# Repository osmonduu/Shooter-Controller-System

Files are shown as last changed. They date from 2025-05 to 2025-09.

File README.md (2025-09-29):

# Shooter Controller System - Custom controllers for shooting games
A controller system that consists of a physical nerf gun controller player camera, aiming, and shooting and a DDR style movement pad. Maps to mouse and keyboard inputs; comptabile with many different games.

# Download the game
This system was designed in collaboration with the UB Fall 2024 CSE410 Game Development team who designed and developed *The Last Run: Project Hope*, a third person zombie parkour shooter game.  

You can download and try *The Last Run: Project Hope* for yourself [here](https://drive.google.com/file/d/1WXuhYaOuxI4oGxkZMJiWuxGikniIIrsq/view).

# About
This was a senior capstone project completed in Spring 2025 in collaboration with Herbert Acheampong and Nathan Fox.

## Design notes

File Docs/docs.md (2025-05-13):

# Movement Pad Documentation

## Important Parts
- Force Sensitive Resistors, a form of potentiometer that changes resistance with applied pressure.  Purchased from [ddrpad.com](https://ddrpad.com/collections/fsr-sensors/products/force-sensitive-resistor-fsr-sensor-square-interlink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)
- Arduino Leonardo, as it supports the keyboard library.  
- Ten 430 Ohm resistors.  The value of the resistor is important because the lower the resistance, the lower the voltage received by the Arduino.  
- Roughly 36 feet of wire are used, running underneath the pad
## Input Scanning 
The code scans through all 10 FSRs, and stores the state in an integer intended to be read in binary or hex.   If the analogue input of the FSR is above a specific threshold, defined in [conf.hpp](../include/conf.hpp). The number has a total of 10 bits that can change, the 10th bit corresponding to the FSR connected to A9, and the 1st bit corresponds to A0.  Below is a diagram that shows what FSR corresponds to what panel on the board, where the top of the diagram is front of the movement pad. There is also markings identifying what each cell is below the acrylic panels and on the underside of the pad.  

Additionally, cell has a red wire that corresponds to the Arduino Leonardo's data pin for that cell.  For example, there is a red wire labeled with number on some masking tape that says it is from Cell 8.  Therefore, it must go to A8.  All the white wires go to the positive voltage line.  This can be either the Arduino or a separate battery like the 12 Volt Dewalt battery.

Unfortunately, there are only 6 analogue pins that are labeled on the Arduino Leonardo even through it supports up to 12 analogue inputs.  This is because some of the digital ports double as analogue ports. Specifically, [digital pin 4 is A6, pin 6 is A7, pin 8 is A8, pin 9 is A9, pin 10 is A10 and pin 12 is A11](https://www.arduino.cc/reference/tr/language/functions/analog-io/analogread/).  Only pins 4 to 9 are used<sup>1</sup>.

1: **ADDENDUM:**  Due to the wire breaking inside of Pin 9, Cell 9 has been moved to port 10/A10.  

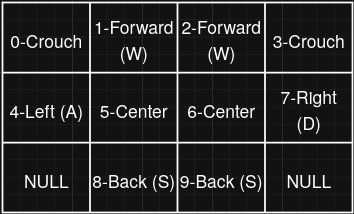
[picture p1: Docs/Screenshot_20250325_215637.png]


## Configuration
Basic configuration can be done in [conf.hpp](../include/conf.hpp).  The threshold value can be configured, and the cells needed to cause a specific action can be changed as well within the define statements.   The code is mostly device agnostic as well.  To define a new device to compile the code to will require updating the [platformio.ini file](../platformio.ini).  This document will not discuss the myriad options provided by Platformio, but you can find that [here.](https://docs.platformio.org/en/latest/)

Additionally, the screwed-in pieces of wood that rest on top of the acrylic panels can be adjusted by screwing in or out the screw.  This can prevent false positives from the wood pushing down the acrylic too tightly.  Changing the threshold can also help.

## Usage

## Common Problems
- Ghost inputs may be caused by the

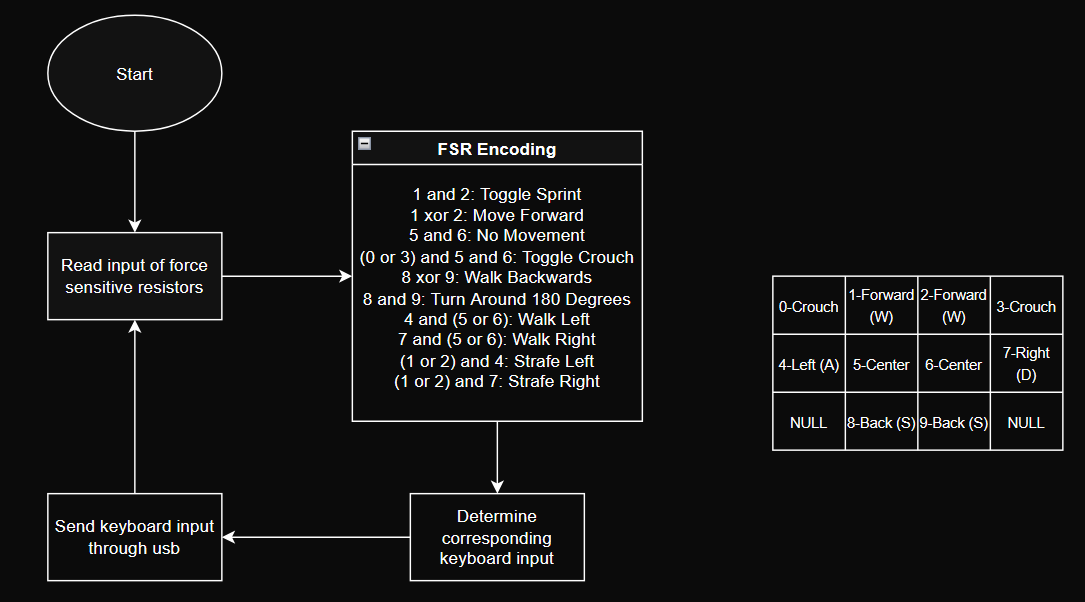
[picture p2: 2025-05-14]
Docs/flowcharts/Flowsheet - Movement Pad.png

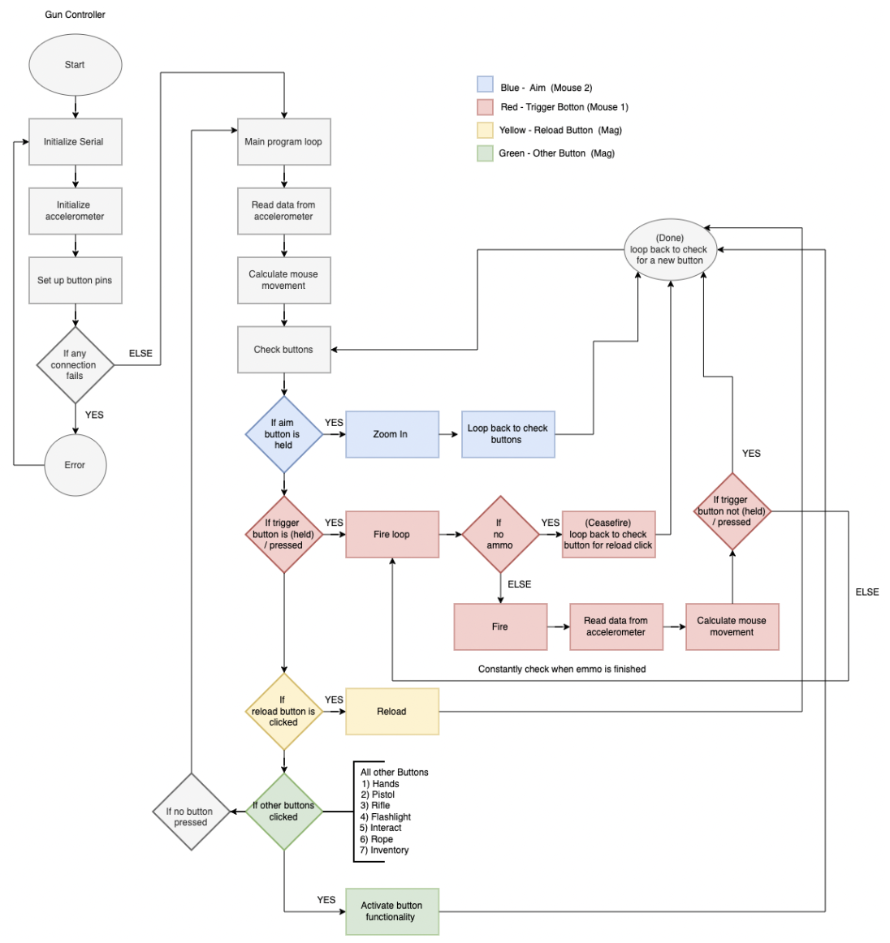
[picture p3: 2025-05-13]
Docs/flowcharts/Flowsheet - Gun Controller.png

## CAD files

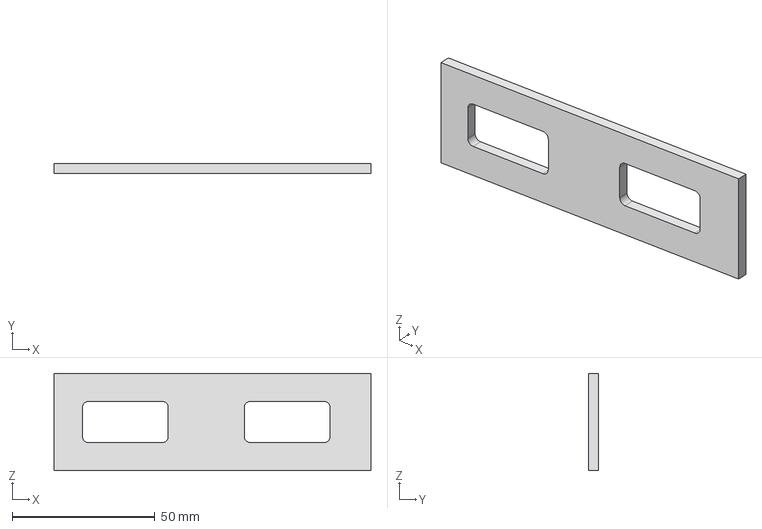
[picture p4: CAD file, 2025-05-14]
3D_Models/arcade_lid_extrusion_3.5.stp
111.0 x 3.50 x 34.0 mm

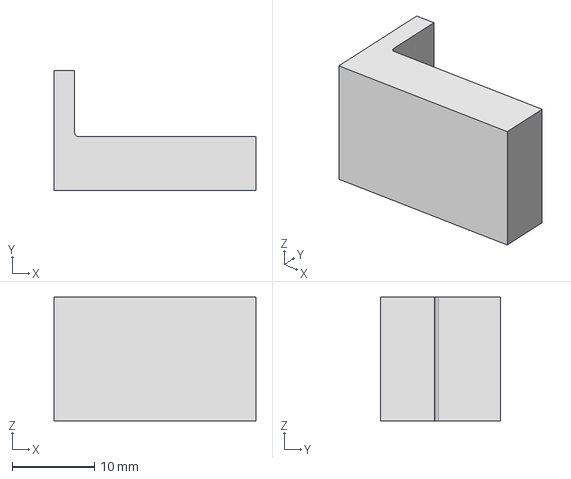
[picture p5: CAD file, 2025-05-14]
3D_Models/small_microswitch_holder.stp
24.5 x 14.5 x 15.0 mm

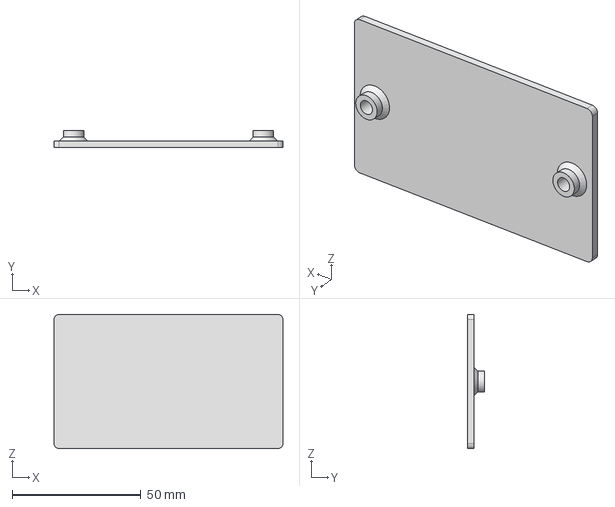
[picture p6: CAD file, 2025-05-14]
3D_Models/medium_backplate.stp
88.9 x 6.50 x 52.1 mm

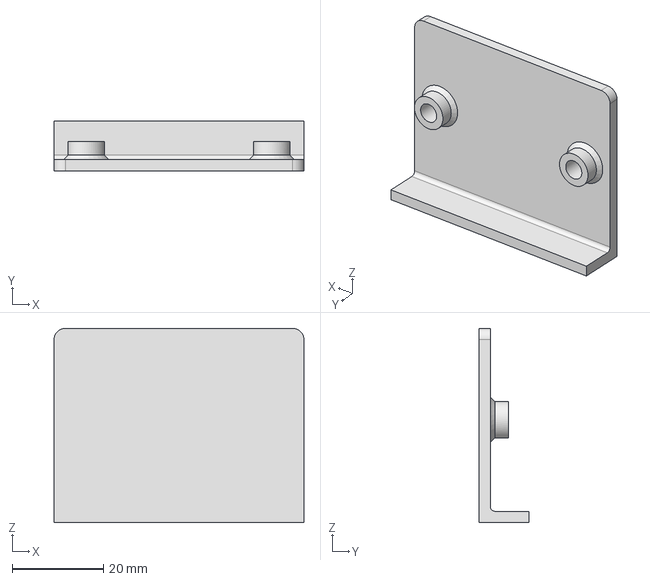
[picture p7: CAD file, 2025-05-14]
3D_Models/small_backplate.stp
54.8 x 11.0 x 42.6 mm

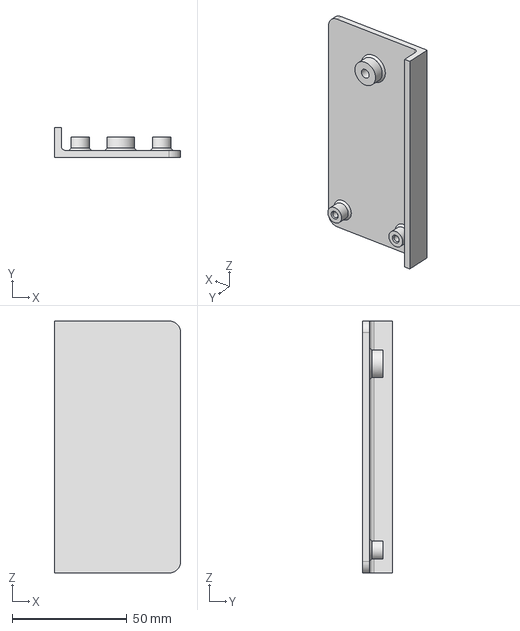
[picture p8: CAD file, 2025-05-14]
3D_Models/long_backplate.stp
55.1 x 13.0 x 110.0 mm

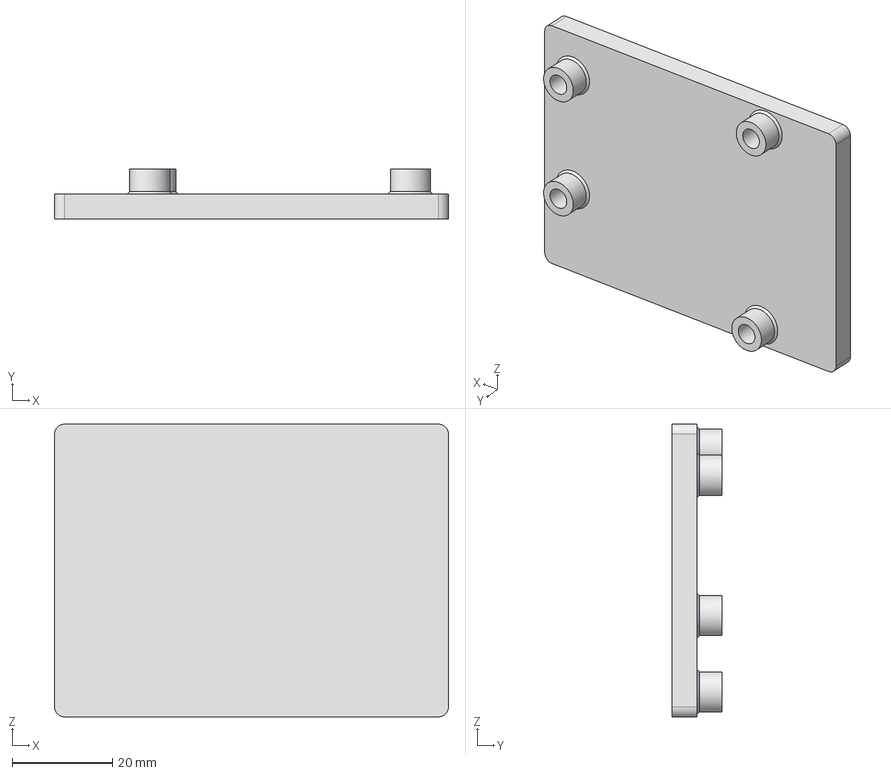
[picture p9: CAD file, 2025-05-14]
3D_Models/leonardo_backplate.stp
78.6 x 10.0 x 58.4 mm

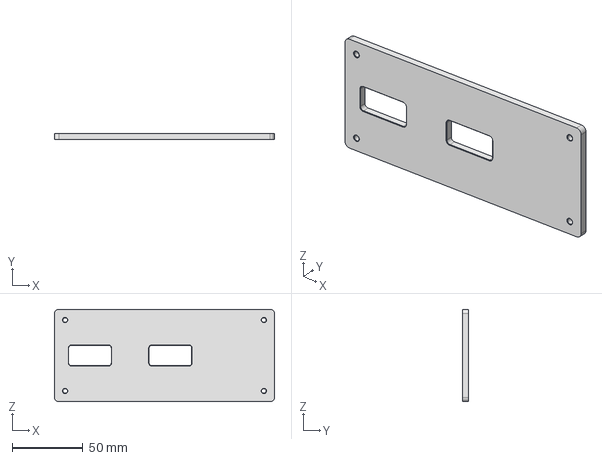
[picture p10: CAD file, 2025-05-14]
3D_Models/arcade_box_lid_iteration3.stp
155.0 x 4.00 x 65.0 mm

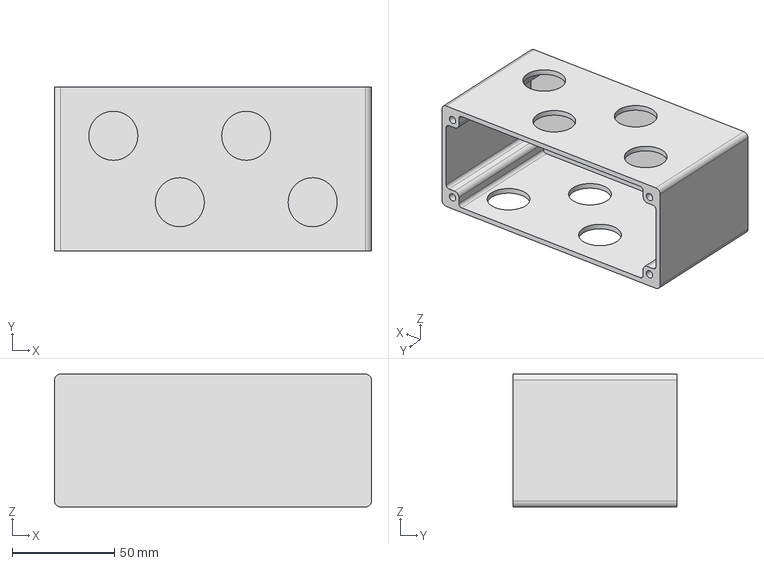
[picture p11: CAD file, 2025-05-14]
3D_Models/arcade_box_iteration3.stp
155.0 x 80.0 x 65.0 mm

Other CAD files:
3D_Models/arcade_box_iteration3.stl
3D_Models/arcade_box_lid_iteration3.stl
3D_Models/arcade_lid_extrusion_3.5.stl
3D_Models/leonardo_backplate.stl
3D_Models/long_backplate.stl
3D_Models/medium_backplate.stl
3D_Models/small_backplate.stl
3D_Models/small_microswitch_holder.stl

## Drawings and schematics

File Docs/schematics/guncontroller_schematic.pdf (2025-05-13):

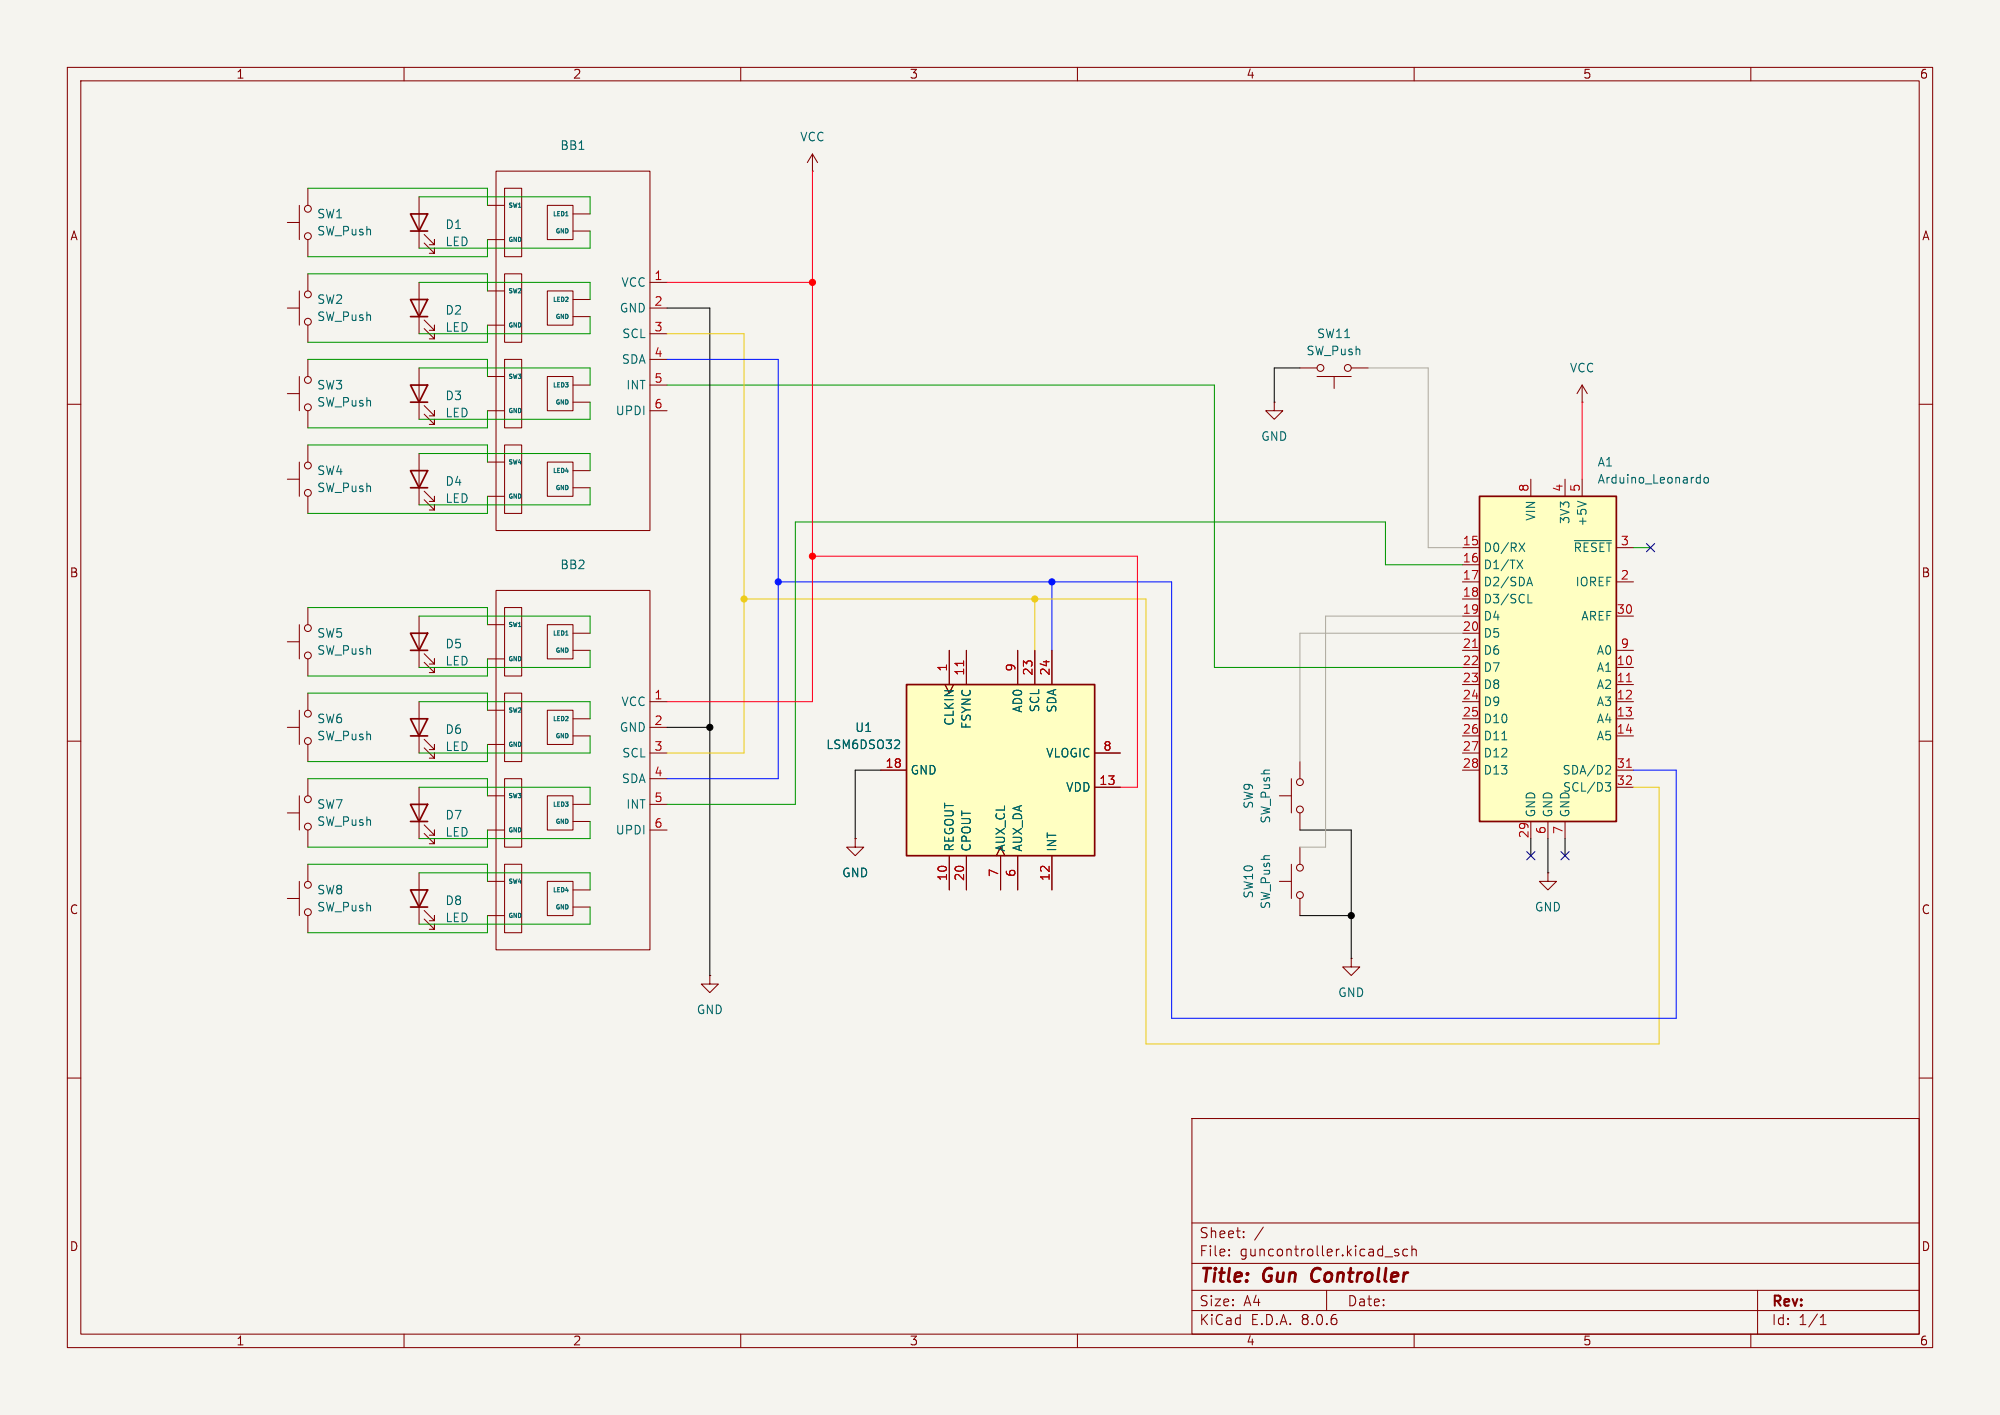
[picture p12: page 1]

Id: 1/1 Title: Gun Controller File: guncontroller.kicad_sch Sheet: /

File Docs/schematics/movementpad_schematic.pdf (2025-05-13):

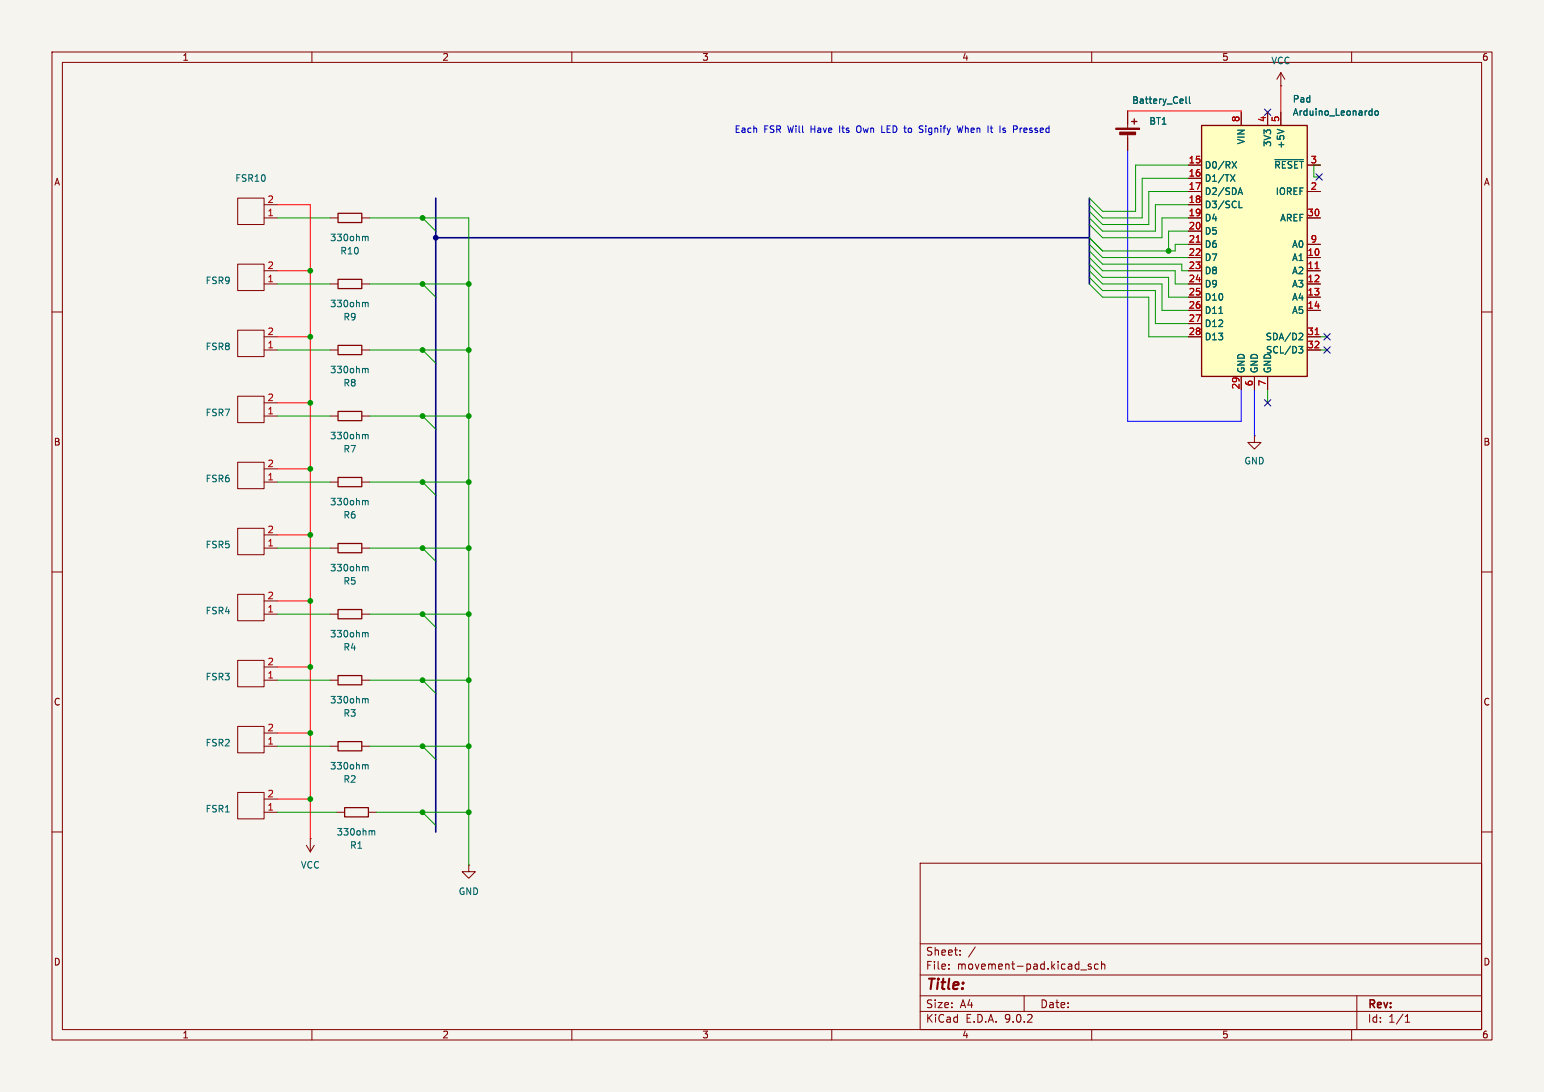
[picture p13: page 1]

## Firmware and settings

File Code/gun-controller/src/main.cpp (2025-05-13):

/* Arcade buttons */
#include "Adafruit_seesaw.h"
#include <seesaw_neopixel.h>
#include <Keyboard.h>
/* Gyromouse */
#include <Adafruit_LSM6DSO32.h>
#include <Mouse.h>

/* Include watchdog library so we can force clear the interrupts */
#include <avr/wdt.h>

//////////////////////////////////////////////////////////////
///                                                        ///
///                     Arcade Buttons                     ///
///                                                        ///
//////////////////////////////////////////////////////////////
#define FIRST_I2C_ADDR 0x3A
#define SECOND_I2C_ADDR 0x3B

// Define switch and LED pins on the breakout board (applies to both)
#define SWITCH1  18  // PA01
#define SWITCH2  19  // PA02
#define SWITCH3  20  // PA03
#define SWITCH4  2   // PA06
#define PWM1  12     // PC00 (LED)
#define PWM2  13     // PC01 (LED)
#define PWM3  0      // PA04 (LED)
#define PWM4  1      // PA05 (LED)

// Subclass Seesaw library
class MySeesaw : public Adafruit_seesaw {
public:
  using Adafruit_seesaw::read;   // bring the protected read() into public scope
};

// Declare breakout board instances
MySeesaw ss1, ss2;

// Breakout board interrupt pins
#define BREAKOUT1_INT_PIN 7
#define BREAKOUT2_INT_PIN 1

// Define pin bit mask used to select which pins on breakout board to read for interrupts
uint32_t mask = ((uint32_t)1 << SWITCH1) | ((uint32_t)1 << SWITCH2) | ((uint32_t)1 << SWITCH3) | ((uint32_t)1 << SWITCH4);

// Flags for seesaw boards ISR
volatile bool seesawInterruptFlag1 = false;
volatile bool seesawInterruptFlag2 = false;
/*----------------------------------------------------------*/

//////////////////////////////////////////////////////////////
///                                                        ///
///                     Gyromouse                          ///
///                                                        ///
//////////////////////////////////////////////////////////////
// Define the primary and secondary fire pins
#define MOUSE1_PIN 4
#define MOUSE2_PIN 5

// Define the recalibration pin
#define RECALIBRATION_PIN 0

// Create sensor instance
Adafruit_LSM6DSO32 dso32;

// Scale factor to convert angular velocity (rad/s) to mouse movement
const float mouseFactor = 100.0;

// Dynamic deadband filter - ignores values (changes) smaller than this (after scaling) 
const float baseDeadband = 0.1;     // Minimum threshold
const float maxDeadband  = 0.8;     // Maximum threshold
const float maxRawExpected = 250;   // Maximum possible reading (after scaling)

// Sensitivity for the mouse movement (applied at the end) - default sensitivity
float sensitivity = 0.25;

// Dynamic scaling (not used right now so kept at default 1.0 values)
// For low speeds, we use a higher scale (for finer control) and at high speeds a lower scale (to reduce overshoot)
const float lowSpeedScale = 1.0;   // Scale factor when the sensor reading is low
const float highSpeedScale = 1.0;  // Scale factor when the sensor reading is high
/*----------------------------------------------------------*/


void setup() {
  Serial.begin(115200);
  // while (!Serial) delay(10);  // <-!!!!!!!!!!!!!!!!!!!!!!!!!!!!!!!!!!!!!!!!!!!!!!!!!!!!!! REMOVE IN FINAL IMPLEMENTATION 
  //////////////////////////////////////////////////////////////
  ///                                                        ///
  ///                     Arcade Buttons                     ///
  ///                                                        ///
  //////////////////////////////////////////////////////////////
  Keyboard.begin(); // Initialize Keyboard
  
  Serial.println(F("Adafruit PID 5296 I2C QT 4x LED Arcade Buttons test!"));

  // Initialize Seesaw devices
  if (!ss1.begin(FIRST_I2C_ADDR)) {
    Serial.println(F("Seesaw 1 not found!"));
    while (1) delay(10);
  }
  if (!ss2.begin(SECOND_I2C_ADDR)) {
    Serial.println(F("Seesaw 2 not found!"));
    while (1) delay(10);
  }

  Serial.println(F("Seesaw started OK!"));

  // Initialize button input pins
  ss1.pinModeBulk(mask, INPUT_PULLUP);
  ss2.pinModeBulk(mask, INPUT_PULLUP);

  // Turn off all LEDs initially
  setVariableLEDs(ss1, 0);
  setVariableLEDs(ss2, 0);

  // Enable GPIO interrupts on seesaw boards using pin mask
  ss1.setGPIOInterrupts(mask, 1);
  ss2.setGPIOInterrupts(mask, 1);
  
  // Attach seesaw boards interrupts to Leonardo's hardware interrupt
  pinMode(BREAKOUT1_INT_PIN, INPUT_PULLUP);
  pinMode(BREAKOUT2_INT_PIN, INPUT_PULLUP);
  attachInterrupt(digitalPinToInterrupt(BREAKOUT1_INT_PIN), seesawISR1, FALLING); 
  attachInterrupt(digitalPinToInterrupt(BREAKOUT2_INT_PIN), seesawISR2, FALLING);
  /*----------------------------------------------------------*/

  //////////////////////////////////////////////////////////////
  ///                                                        ///
  ///                     Gyromouse                          ///
  ///                                                        ///
  //////////////////////////////////////////////////////////////
  // Start USB mouse functionality
  Mouse.begin();

  Serial.println("Adafruit LSM6DSO32 Mouse Begin");

  // Initialize sensor using I2C
  if (!dso32.begin_I2C()) {
    Serial.println("Failed to find LSM6DSO32 chip!");
    while(1) delay(10);
  }
  Serial.println("LSM6DSO32 found!");

  // Set ranges and data rates for the gyroscope
  dso32.setAccelDataRate(LSM6DS_RATE_SHUTDOWN);   // shutdown the accelerometer since we are not using it
  dso32.setGyroRange(LSM6DS_GYRO_RANGE_125_DPS);
  // dso32.setGyroDataRate(LSM6DS_RATE_1_66K_HZ);
  dso32.setGyroDataRate(LSM6DS_RATE_833_HZ);

  // Init the pins for the primary and secondary fire microswitches and the recalibration microswitch
  pinMode(MOUSE1_PIN, INPUT_PULLUP);
  pinMode(MOUSE2_PIN, INPUT_PULLUP);
  pinMode(RECALIBRATION_PIN, INPUT_PULLUP);
  /*----------------------------------------------------------*/
}

void seesawISR1() {
  seesawInterruptFlag1 = true;
}
void seesawISR2() {
  seesawInterruptFlag2 = true;
}

// Global variables to track previous mouse button states
bool prevMouse1State = HIGH;
bool prevMouse2State = HIGH;

// Used to reset the controller whenever the arcade buttons get stuck. This bypasses the need to unplug and replug the controller.
void reboot() {
  // Force reset the arduino using watchdog timer
  wdt_disable();
  wdt_enable(WDTO_15MS);
  // Software reset the seesaw boards to clear the GPIO interrupts
  bool ss1Reset = ss1.SWReset();
  bool ss2Reset = ss2.SWReset();
  // Read GPIO INTFLAG to read and clear the remaining interrupts from both seesaw boards
  uint8_t byte_buf[4];
  ss1.read(SEESAW_GPIO_BASE, SEESAW_GPIO_INTFLAG, byte_buf, (uint8_t)4, 0);
  ss2.read(SEESAW_GPIO_BASE, SEESAW_GPIO_INTFLAG, byte_buf, (uint8_t)4, 0);
  setup();
  // while (1) {}
}

void loop() {
  //////////////////////////////////////////////////////////////
  ///                                                        ///
  ///                     Arcade Buttons                     ///
  ///                                                        ///
  //////////////////////////////////////////////////////////////
  if (seesawInterruptFlag1) {
    checkButtons(ss1, BREAKOUT1_INT_PIN, true);
    seesawInterruptFlag1 = false;
  }
  if (seesawInterruptFlag2) {
    checkButtons(ss2, BREAKOUT2_INT_PIN, false);
    seesawInterruptFlag2 = false;
  }
  /*----------------------------------------------------------*/

  //////////////////////////////////////////////////////////////
  ///                                                        ///
  ///                     Gyromouse                          ///
  ///                                                        ///
  //////////////////////////////////////////////////////////////
  bool currMouse1State = digitalRead(MOUSE1_PIN);
  bool currMouse2State = digitalRead(MOUSE2_PIN);


  // Mouse cursor movement logic
  if (digitalRead(RECALIBRATION_PIN) == LOW) {
    // Press the reclibration, mouse1, and mouse2 buttons at the same time to reset the gun. Useful for getting the arcade buttons to become unstuck.
    if (currMouse1State == LOW && currMouse2State == LOW) {
      reboot();
    }
    // Don't update mouse movement to stop mouse cursor from moving while recalibration button is held down.
    // Only change sensitivity on a transition from HIGH -> LOW
    if (currMouse1State == LOW && prevMouse1State == HIGH) {
      sensitivity += 0.05;
      // Clamp to prevent too high sens
      if (sensitivity > 3.0) sensitivity = 3.0;
      delay(5);
      // Debug
      // Serial.print("Sensitivity increased: "); Serial.println(sensitivity);
    }
    // Only change sensitivity on a transition from HIGH -> LOW
    if (currMouse2State == LOW && prevMouse2State == HIGH) {
      sensitivity -= 0.05;
      // Clamp to prevent negative sens
      if (sensitivity < 0.05) sensitivity = 0.05;
      delay(5);
      // Debug
      // Serial.print("Sensitivity decreased: "); Serial.println(sensitivity);
    }

    // Disable mouse buttons by forcibly releasing them
    Mouse.release(MOUSE_LEFT);
    Mouse.release(MOUSE_RIGHT);
  } else {
      // Process mouse movement
      updateMouseMovement();

      // Check mouse button microswitches
      if (currMouse1State == LOW) {
        Mouse.press(MOUSE_LEFT);
      } else {
          Mouse.release(MOUSE_LEFT);
      }
      if (currMouse2State == LOW) {
          Mouse.press(MOUSE_RIGHT);
      } else {
          Mouse.release(MOUSE_RIGHT);
      }
  }


  // Store the current states for next iteration
  prevMouse1State = currMouse1State;
  prevMouse2State = currMouse2State;
  /*----------------------------------------------------------*/

  delay(0); // lower delay for the smoother mouse movement
}

void updateMouseMovement() {
  // Get new normalized sensor events
  sensors_event_t accel, gyro, temp;
  dso32.getEvent(&accel, &gyro, &temp);

  // Read gyroscope values (angular velocity in rad/s) and scale
  int rawX = gyro.gyro.z * mouseFactor;
  int rawY = gyro.gyro.y * mouseFactor;

  // Calculate dynamic deadband for each axis based on current speed
  float dynDeadbandX = baseDeadband + (maxDeadband - baseDeadband) * (min(abs(rawX), maxRawExpected) / maxRawExpected);
  float dynDeadbandY = baseDeadband + (maxDeadband - baseDeadband) * (min(abs(rawY), maxRawExpected) / maxRawExpected);

  // Calculate dynamic scaling factors
  float speedFactorX = min(abs(rawX), maxRawExpected) / maxRawExpected;
  float dynamicScaleX = lowSpeedScale + (highSpeedScale - lowSpeedScale) * speedFactorX;
  
  float speedFactorY = min(abs(rawY), maxRawExpected) / maxRawExpected;
  float dynamicScaleY = lowSpeedScale + (highSpeedScale - lowSpeedScale) * speedFactorY;

  // Apply the dynamic deadband filtering and scaling - if the absolute value is less than the dynamic threshold set to 0. Otherwise, scale.
  int xMovement = (abs(rawX) > dynDeadbandX) ? int(rawX * dynamicScaleX) : 0;
  int yMovement = (abs(rawY) > dynDeadbandY) ? int(rawY * dynamicScaleY) : 0;

  // Invert axis to correct mouse orientation - adjust depending on how you hold the device
  if (xMovement != 0) xMovement = -xMovement;
  // if (yMovement != 0) yMovement = -yMovement;

  // Move the mouse based off the gyroscope readings, no mouse wheel
  Mouse.move(xMovement*sensitivity, yMovement*sensitivity, 0);

  // Debug output
  // Serial.print("Raw Gyro X: "); Serial.print(gyro.gyro.z);
  // Serial.print(" | Raw Gyro Y: "); Serial.print(gyro.gyro.y);
  // Serial.print(" | DynDeadbandX: "); Serial.print(dynDeadbandX);
  // Serial.print(" | DynDeadbandY: "); Serial.print(dynDeadbandY);
  // Serial.print(" | DynamicScaleX: "); Serial.print(dynamicScaleX);
  // Serial.print(" | DynamicScaleY: "); Serial.print(dynamicScaleY);
  // Serial.print(" | MouseX: "); Serial.print(xMovement * sensitivity);
  // Serial.print(" | MouseY: "); Serial.print(yMovement * sensitivity);
  // Serial.print("\n");
}

// Used as a debounce to fix single button spam 'sticking' and freezing entire breakout board
bool lastSwitch1 = false, lastSwitch2 = false, lastSwitch3 = false, lastSwitch4 = false;


void checkButtons(MySeesaw &ss, int intPin, bool isFirst) {
  // digitalReadBulk will return mask if no button is pressed. If a button is pressed, its bit position will be 0.
  uint32_t buttonStates = ss.digitalReadBulk(mask);
  
  // Serial.print("Entered checkButtons(), Returned Mask: "); Serial.print(buttonStates); Serial.print("\n");

  bool switch1 = !(buttonStates & (1UL << SWITCH1));
  bool switch2 = !(buttonStates & (1UL << SWITCH2));
  bool switch3 = !(buttonStates & (1UL << SWITCH3));
  bool switch4 = !(buttonStates & (1UL << SWITCH4));

  // Mapping button pressed to keyboard inputs
  if (switch1 != lastSwitch1) {
    if (switch1) {
      Keyboard.press(isFirst ? 'q' : '4');
    } else {
      Keyboard.release(isFirst ? 'q' : '4');
    }
    lastSwitch1 = switch1;
  }

  if (switch2 != lastSwitch2) {
    if (switch1 && switch2) {
      // Keyboard.press(KEY_UP_ARROW);
      // Keyboard.release(KEY_UP_ARROW);
      Mouse.move(0,0,1);
    } 
    else {
        if (switch2) {
          Keyboard.press(isFirst ? '1' : 'f');
        } else {
          Keyboard.release(isFirst ? '1' : 'f');
        }
    }
    lastSwitch1 = switch1;
    lastSwitch2 = switch2;
  }

  if (switch3 != lastSwitch3) {
    if (switch1 && switch3) {
      // Keyboard.press(KEY_DOWN_ARROW);
      // Keyboard.release(KEY_DOWN_ARROW);
      Mouse.move(0,0,-1);
    }
    else if (switch3 && switch4) {
      Keyboard.press(' ');
      Keyboard.release(' ');
      delay(15);
      Keyboard.press(' ');
      Keyboard.release(' ');
    }
    else {
        if (switch3) {
          Keyboard.press(isFirst ? '2' : 'r');
        } else {
          Keyboard.release(isFirst ? '2' : 'r');
        }
    }
    lastSwitch1 = switch1;
    lastSwitch3 = switch3;
    lastSwitch4 = switch4;
  }

  if (switch4 != lastSwitch4) {
    // Double jump whenever switch 3 and switch 4 is pressed
    if (switch3 && switch4) {
      Keyboard.press(' ');
      Keyboard.release(' ');
      delay(15);
      Keyboard.press(' ');
      Keyboard.release(' ');
    }
    else {
      if (switch4) {
        Keyboard.press(isFirst ? '3' : 'e');
      } else {
        Keyboard.release(isFirst ? '3' : 'e');
      }
    }
    lastSwitch3 = switch3; 
    lastSwitch4 = switch4;
  }

  // LED behavior: turn on when pressed, off otherwise
  setLEDs(ss, switch1, switch2, switch3, switch4);

  // Serial.print("Button states "); Serial.print("BB"); Serial.print(isFirst ? "1: " : "2: ");
  // Serial.print(switch1); Serial.print(" ");
  // Serial.print(switch2); Serial.print(" ");
  // Serial.print(switch3); Serial.print(" ");
  // Serial.print(switch4); Serial.println();
}


// Function to set LED states
void setLEDs(MySeesaw &ss, bool led1, bool led2, bool led3, bool led4) {
  ss.analogWrite(PWM1, led1 ? 127 : 0);
  ss.analogWrite(PWM2, led2 ? 127 : 0);
  ss.analogWrite(PWM3, led3 ? 127 : 0);
  ss.analogWrite(PWM4, led4 ? 127 : 0);
}

// Function to turn off all LEDs
void setVariableLEDs(MySeesaw &ss, int brightness) {
  ss.analogWrite(PWM1, brightness);
  ss.analogWrite(PWM2, brightness);
  ss.analogWrite(PWM3, brightness);
  ss.analogWrite(PWM4, brightness);
}

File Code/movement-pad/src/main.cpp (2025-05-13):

#include <main.hpp>
#include <conf.hpp>
#include <util.hpp>
// #include <Joystick.h>

// static bool toggleSprint = false;

// A6 = D4, A7 = D6, A8 = D8, A9 = D9
int apinArray[] = {A0, A1, A2, A3, A4, A5, A6, A7, A8, A10}; // change because the wire broke in A9
bool toggleSprint = false;
bool toggleCrouch = false;


int timer = 0; // used to display time in since program started

// heaviest cell


void setup()
{
    Serial.begin(9600);
    pinMode(TX_PIN, INPUT); // if high then it means keyboard transmission is enabled
    pinMode(LED_ZERO, OUTPUT); 
    pinMode(LED_ONE, OUTPUT);
    pinMode(LED_TWO, OUTPUT);
    pinMode(LED_THREE, OUTPUT);
    pinMode(LED_FOUR, OUTPUT);
    pinMode(A10, INPUT); // debugging pin
    pinMode(HALT_PIN, INPUT_PULLUP);

    
    // 0x0C is form feed/new page, clear the serial terminal from all the BLOCKING messages
    Serial.write(0xC);
    // Serial.println("STARTING PROGRAM!!!");
    delay(1000); 
}

void loop()
{
    while(digitalRead(HALT_PIN) == HIGH);

    timer += 1;
    // Serial.println("LOOPING");
    // put your main code here, to run repeatedly:
    
    int states = updateState();
    char fstr[STRSIZE];
    

    int f = snprintf(fstr, STRSIZE, "[MAIN] State is: %#4x, time is: %4i" , states, timer);
    if (f >= 0 && f < STRSIZE)
    {
      Serial.println(fstr);
    }

    char sendKey  = '\0'; // default to null, this will be the key the arduino sends
    char strafeKey = '\0'; // default to null, used for strafing
    bool strafing = false;    

    // exclusively to over-write state when debugging keyboard input
    if(digitalRead(2) == HIGH){
      sendKey = '?'; // should be impossible under normal circumstances
    }

    delay(100); // adjust for sensitivity when polling



    switch (states)
    {
    // docs.md explains this switch statement
  
    case WALK1:
    case WALK2:
    case WALK3:
    case WALK4:
      // look for walk input
      sendKey = 'w';
      break;
    case SPRINT:
      // combination of shift and w
      toggleSprint = !toggleSprint; // invert toggle crouch
      break;
    case TOG_CROUCH:
      toggleCrouch = !toggleCrouch;
      break;
    case RIGHT1:
    case RIGHT2:
      sendKey = 'd';
      break;
    case LEFT1:
    case LEFT2:
      sendKey = 'a';
      break;
    case STRAFE_L1:
    case STRAFE_L2:
      sendKey = 'w';
      strafeKey = 'a';
      strafing = true;
      break;
    case STRAFE_R1:
    case STRAFE_R2:
      sendKey = 'w';
      strafeKey = 'd';
      strafing = true;
      break;
    case BACKWARDS1:
    case BACKWARDS2:
    case BACKWARDS3:
    case BACKWARDS4:
    case BACKWARDS5:
      sendKey = 's';
      break;
    case STAYSTILL:
      sendKey = '\0';
      break;
    case JUMP:
      sendKey = ' ';
      break;
    default:
        sendKey = '\0'; // if input combo is wrong or user is standing in the middle, send a null for now
    }

    // for debugging, allows me to turn sending keyboard input off
    if (digitalRead(TX_PIN) == HIGH)
    {
        digitalWrite(TX_LED, HIGH); // show that keyboard output will be written
        Serial.println("WRITING OUTPUT");
        Keyboard.begin(KeyboardLayout_en_US);

        if (toggleCrouch){
          Keyboard.press(KEY_LEFT_CTRL);
        } else {
          Keyboard.release(KEY_LEFT_CTRL);
        }

        if (toggleSprint){
          Keyboard.press(KEY_LEFT_SHIFT);
        } else {
          Keyboard.release(KEY_LEFT_SHIFT);
        }

        if (strafing){
          Keyboard.press(strafeKey);
        }

        Keyboard.press(sendKey);
        delay(50);
        Keyboard.release(sendKey);
        Keyboard.release(strafeKey);
        
        Keyboard.end();
    }
    else
    {
        digitalWrite(TX_LED, LOW);
    }

    // Serial.write(0x0C); // new page   
}

int updateState()
{

    // using A0 - A8 and A10
    int state = 0;
    int heaviest_cell[2] = {NA, 0}; // i can brute force this array into a really shitty tuple
    // represents the cell ID and the analogue value of the current heaviest pin
    // 10 pins read, max of 9 - update to go to 10 to display A11 which should be D12
    for (int pindex = 9; pindex > -1; pindex--)
    {
        int pin = apinArray[pindex];
        int aVal = analogRead(pin); // weight upon the current cell
        // bitshift to store pin states in one integer
        state = state << 1; // LEFT SHIFT LEFT SHIFT LEFT SHIFT
        twoChar twoCharPin = readableAnalogPin(pin);
        char str[STRSIZE];

        if(heaviest_cell[1] < aVal){
          // if there is a heavier weight upon the previous recorded weight, update the new cell
          heaviest_cell[0] = pindex; // current pin we're looking at
          heaviest_cell[1] = aVal; // new weight 
        }

        // 600 is the default threshold value, configured in conf.hpp
        if (aVal > THRESHOLD)
        {
            state += 1;
        }
        else
        {
            state += 0; // i know this does nothing, its there just for clarity
        }

        snprintf(str, 100, "%c%c reads %.4i.  Therefore, state is: %#.4x", twoCharPin.c1, twoCharPin.c2, aVal, state);
        Serial.println(str);
    }

    // if the heaviest cell is actually something interesting, display it on the LEDs
    if (heaviest_cell[0] != NA){

      // LOW is defined as 0, HIGH defined as 1.  We can avoid uncessesary if statements by using 
      // a bitwise AND for what to write in digitalWrite()
      digitalWrite(LED_ZERO, heaviest_cell[0] & 1); // 2^0
      digitalWrite(LED_ONE, heaviest_cell[0] & 2); // 2^1
      digitalWrite(LED_TWO, heaviest_cell[0] & 4); // 2^2
      digitalWrite(LED_THREE, heaviest_cell[0] & 8); // 2^3
      digitalWrite(LED_FOUR, heaviest_cell[0] & 16); // 2$4


      // this will write out the number of the heaviest cell in binary
    }

    return state;
}

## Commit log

2025-05-13 Updated schematics and code
    [guncontroller.kicad_sch, movement-pad.kicad_sch]
2025-05-14 Renamed "controller" dir and added cad files
    [arcade_box_iteration3.ipt, arcade_box_lid_iteration3.ipt, arcade_lid_extrusion_3.5.ipt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]
2025-05-14 changed CAD filetypes and added stl files
    [arcade_box_iteration3.ipt, arcade_box_iteration3.stl, arcade_box_iteration3.stp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]
2025-05-14 Updated pad flowsheet
